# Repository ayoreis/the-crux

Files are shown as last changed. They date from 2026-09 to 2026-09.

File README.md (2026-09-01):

# The Crux

A minimal 3x10 ortholinear keyboard. Driven by a RP2040 with [RMK](https://rmk.rs) + [Vial](https://get.vial.today).

I've always wanted to make a keyboard, I actually started this one with much more ambitious ideas (you can find them in my earlier journals, or by going back the commit history) but realized I should start out with something simpler. So I made this! It was quite nice, and maybe I'll improve it with my previous ideas one-by-one :)

Schematic
PCB
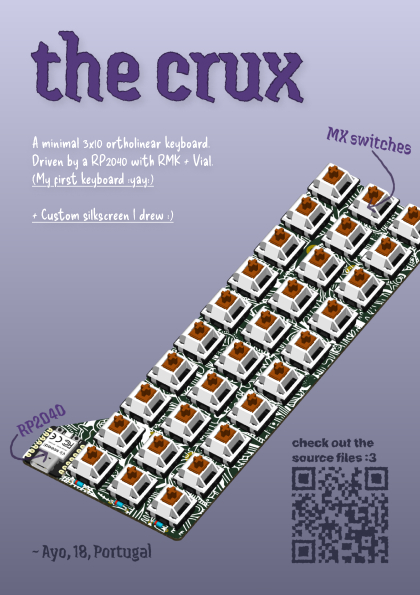
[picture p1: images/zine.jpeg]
Zine


# File structure and assembly

At the top-level there's a general "bom.csv". Then the directories:

- "pcb/" contains a KiCad project and generated production files with KiCAD JLCPCB tools under "pcb/jlcpcb/".
- "standoffs/" contains a FreeCAD file and an exported "standoff.step".
- "images/" contains the images above and the zine in PDF format.
- "firmware/" contains the RMK and Vial firmware. With the compiled UF2 file at "firmware/The_Crux.uf2".

The standoffs are press-fit into the PCB, it's parametric so it can be tuned for different 3D printers.

---

_[Also see this project on Fallout.](https://fallout.hackclub.com/projects/4383)_

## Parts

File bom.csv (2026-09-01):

Description | Cost | Count | Link | Notes
PCB | €24.95 | 1 | https://jlcpcb.com/ | Including shipping
Seeed Studio XIAO RP2040 | €16.27 | 1 | https://pt.farnell.com/seeed-studio/102010428/xiao-board-arm-arduino-board/dp/4060348 | Including shipping
Switches | €17.27 | 3 | https://deltakeyco.com/products/cherry-mx2a-black?variant=49356598411605 | Including shipping
Keycaps | €14.38 | 1 | https://pt.aliexpress.com/item/4000354001038.html | Including shipping
Standoffs | €0.00 | 1 | N/A | 3D printed at home
Total | €72.87

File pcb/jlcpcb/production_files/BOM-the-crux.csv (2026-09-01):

Comment | Designator | Footprint | LCSC | Quantity
XIAO-RP2040-SMD | U1 | XIAO-RP2040-SMD |  | 1
SW_Push | SW30 | SW_Cherry_MX_1.00u_PCB |  | 1
SW_Push | SW29 | SW_Cherry_MX_1.00u_PCB |  | 1
SW_Push | SW28 | SW_Cherry_MX_1.00u_PCB |  | 1
SW_Push | SW27 | SW_Cherry_MX_1.00u_PCB |  | 1
SW_Push | SW26 | SW_Cherry_MX_1.00u_PCB |  | 1
SW_Push | SW25 | SW_Cherry_MX_1.00u_PCB |  | 1
SW_Push | SW24 | SW_Cherry_MX_1.00u_PCB |  | 1
SW_Push | SW23 | SW_Cherry_MX_1.00u_PCB |  | 1
SW_Push | SW22 | SW_Cherry_MX_1.00u_PCB |  | 1
SW_Push | SW21 | SW_Cherry_MX_1.00u_PCB |  | 1
SW_Push | SW20 | SW_Cherry_MX_1.00u_PCB |  | 1
SW_Push | SW19 | SW_Cherry_MX_1.00u_PCB |  | 1
SW_Push | SW18 | SW_Cherry_MX_1.00u_PCB |  | 1
SW_Push | SW17 | SW_Cherry_MX_1.00u_PCB |  | 1
SW_Push | SW16 | SW_Cherry_MX_1.00u_PCB |  | 1
SW_Push | SW15 | SW_Cherry_MX_1.00u_PCB |  | 1
SW_Push | SW14 | SW_Cherry_MX_1.00u_PCB |  | 1
SW_Push | SW13 | SW_Cherry_MX_1.00u_PCB |  | 1
SW_Push | SW12 | SW_Cherry_MX_1.00u_PCB |  | 1
SW_Push | SW11 | SW_Cherry_MX_1.00u_PCB |  | 1
SW_Push | SW10 | SW_Cherry_MX_1.00u_PCB |  | 1
SW_Push | SW9 | SW_Cherry_MX_1.00u_PCB |  | 1
SW_Push | SW8 | SW_Cherry_MX_1.00u_PCB |  | 1
SW_Push | SW7 | SW_Cherry_MX_1.00u_PCB |  | 1
SW_Push | SW6 | SW_Cherry_MX_1.00u_PCB |  | 1
SW_Push | SW5 | SW_Cherry_MX_1.00u_PCB |  | 1
SW_Push | SW4 | SW_Cherry_MX_1.00u_PCB |  | 1
SW_Push | SW3 | SW_Cherry_MX_1.00u_PCB |  | 1
SW_Push | SW2 | SW_Cherry_MX_1.00u_PCB |  | 1
SW_Push | SW1 | SW_Cherry_MX_1.00u_PCB |  | 1
D | D4 | D_DO-35_SOD27_P7.62mm_Horizontal |  | 1
D | D11 | D_DO-35_SOD27_P7.62mm_Horizontal |  | 1
D | D3 | D_DO-35_SOD27_P7.62mm_Horizontal |  | 1
D | D27 | D_DO-35_SOD27_P7.62mm_Horizontal |  | 1
D | D23 | D_DO-35_SOD27_P7.62mm_Horizontal |  | 1
D | D30 | D_DO-35_SOD27_P7.62mm_Horizontal |  | 1
D | D25 | D_DO-35_SOD27_P7.62mm_Horizontal |  | 1
D | D7 | D_DO-35_SOD27_P7.62mm_Horizontal |  | 1
D | D14 | D_DO-35_SOD27_P7.62mm_Horizontal |  | 1
D | D2 | D_DO-35_SOD27_P7.62mm_Horizontal |  | 1
D | D26 | D_DO-35_SOD27_P7.62mm_Horizontal |  | 1
D | D5 | D_DO-35_SOD27_P7.62mm_Horizontal |  | 1
D | D19 | D_DO-35_SOD27_P7.62mm_Horizontal |  | 1
D | D8 | D_DO-35_SOD27_P7.62mm_Horizontal |  | 1
D | D15 | D_DO-35_SOD27_P7.62mm_Horizontal |  | 1
D | D12 | D_DO-35_SOD27_P7.62mm_Horizontal |  | 1
D | D18 | D_DO-35_SOD27_P7.62mm_Horizontal |  | 1
D | D10 | D_DO-35_SOD27_P7.62mm_Horizontal |  | 1
D | D22 | D_DO-35_SOD27_P7.62mm_Horizontal |  | 1
D | D29 | D_DO-35_SOD27_P7.62mm_Horizontal |  | 1
D | D6 | D_DO-35_SOD27_P7.62mm_Horizontal |  | 1
D | D24 | D_DO-35_SOD27_P7.62mm_Horizontal |  | 1
D | D13 | D_DO-35_SOD27_P7.62mm_Horizontal |  | 1
D | D17 | D_DO-35_SOD27_P7.62mm_Horizontal |  | 1
D | D28 | D_DO-35_SOD27_P7.62mm_Horizontal |  | 1
D | D1 | D_DO-35_SOD27_P7.62mm_Horizontal |  | 1
D | D20 | D_DO-35_SOD27_P7.62mm_Horizontal |  | 1
D | D21 | D_DO-35_SOD27_P7.62mm_Horizontal |  | 1
D | D16 | D_DO-35_SOD27_P7.62mm_Horizontal |  | 1
D | D9 | D_DO-35_SOD27_P7.62mm_Horizontal |  | 1

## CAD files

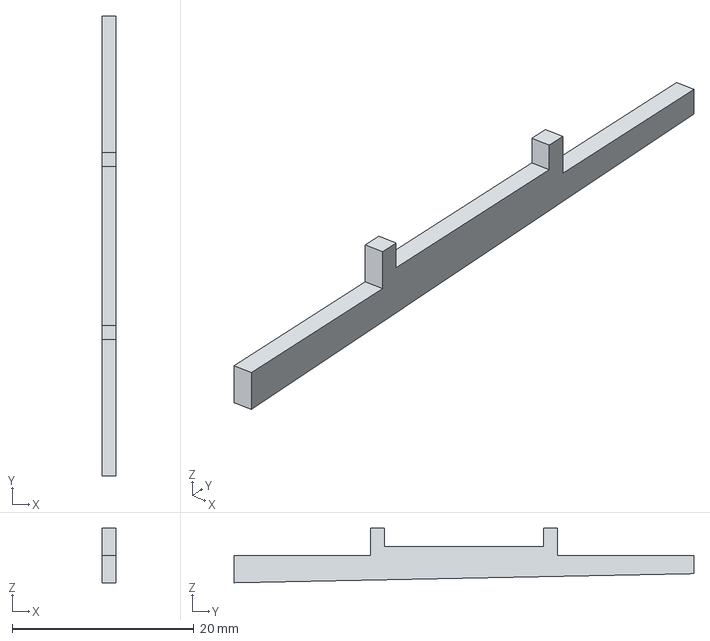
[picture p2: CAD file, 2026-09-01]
standoffs/standoffs.step
1.56 x 50.6 x 6.00 mm

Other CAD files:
standoffs/standoffs.FCStd

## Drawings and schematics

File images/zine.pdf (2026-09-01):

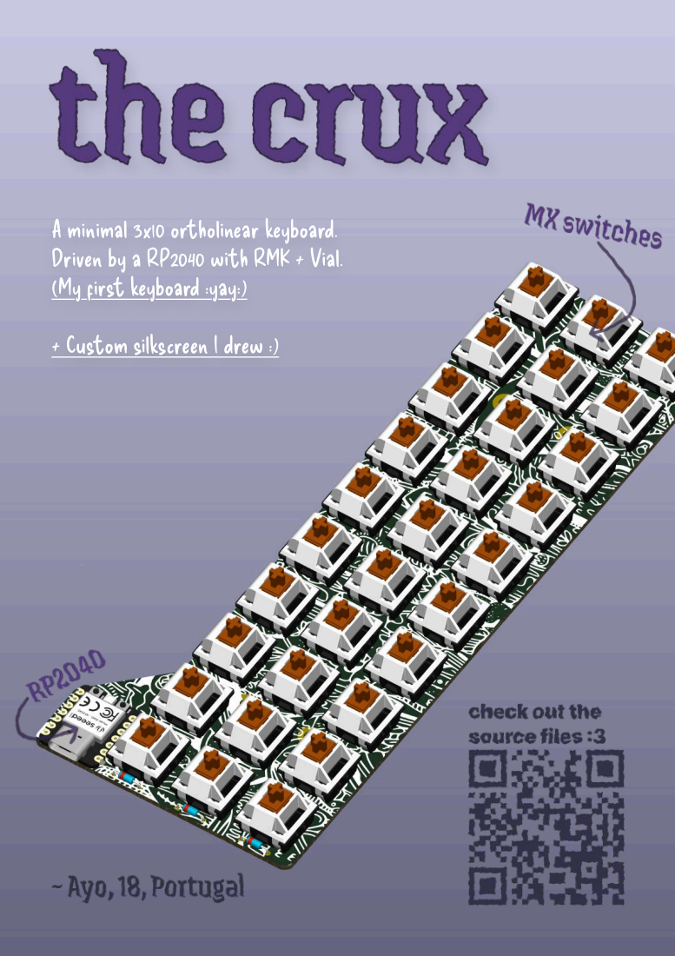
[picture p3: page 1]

A minimal 3x10 ortholinear keyboard.
Driven by a RP2040 wi th RMK + Vial.
(My first keyboard :yay:)

+ Custom silkscreen I drew :)

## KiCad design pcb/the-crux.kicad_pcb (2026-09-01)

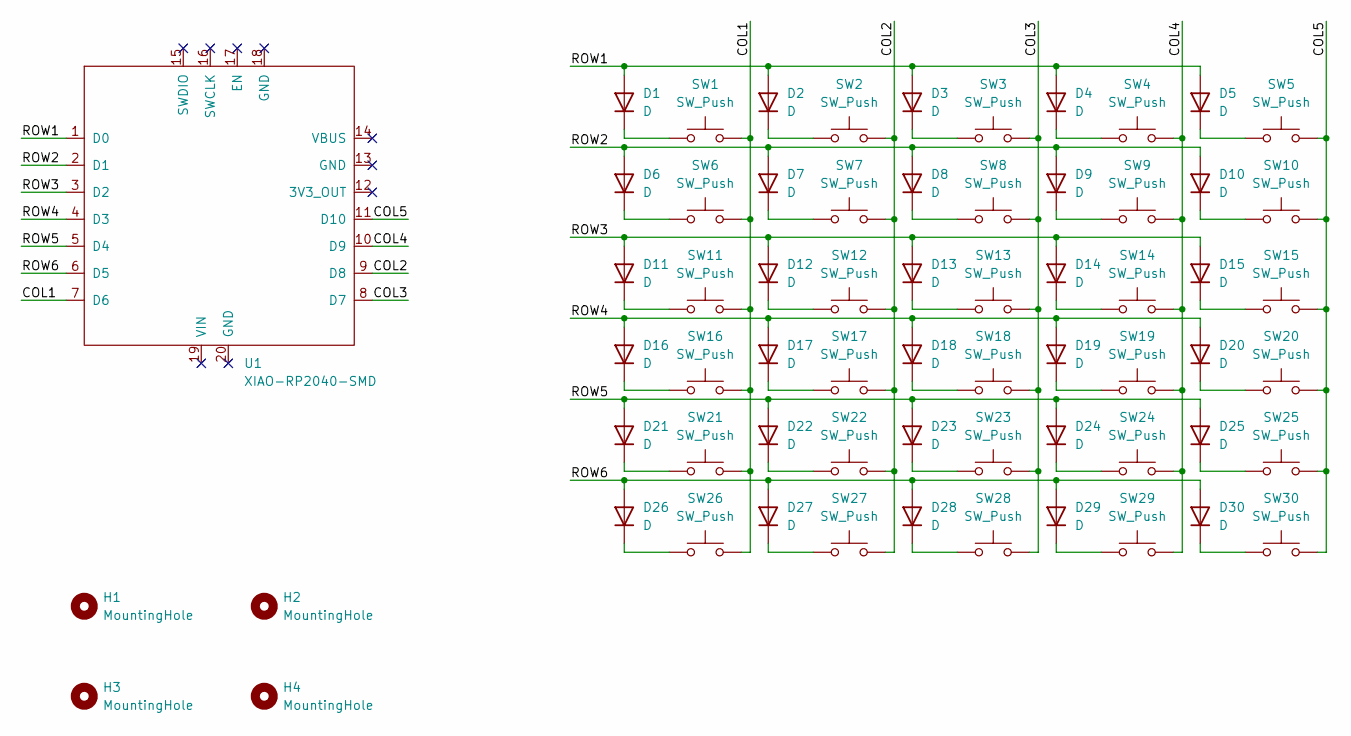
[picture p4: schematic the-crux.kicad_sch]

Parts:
D1, D2, D3, D4, D5, D6, D7, D8, D9, D10, D11, D12, D13, D14, D15, D16, D17, D18, D19, D20, D21, D22, D23, D24, D25, D26, D27, D28, D29, D30: D; D_DO-35_SOD27_P7.62mm_Horizontal
H1, H2, H3, H4: MountingHole; MountingHole_2.2mm_M2_Pad
SW1, SW2, SW3, SW4, SW5, SW6, SW7, SW8, SW9, SW10, SW11, SW12, SW13, SW14, SW15, SW16, SW17, SW18, SW19, SW20, SW21, SW22, SW23, SW24, SW25, SW26, SW27, SW28, SW29, SW30: SW_Push; SW_Cherry_MX_1.00u_PCB
U1: XIAO-RP2040-SMD

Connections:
/COL1: SW1.2, SW6.2, SW11.2, SW16.2, SW21.2, SW26.2, U1.7 (D6)
/COL2: SW2.2, SW7.2, SW12.2, SW17.2, SW22.2, SW27.2, U1.9 (D8)
/COL3: SW3.2, SW8.2, SW13.2, SW18.2, SW23.2, SW28.2, U1.8 (D7)
/COL4: SW4.2, SW9.2, SW14.2, SW19.2, SW24.2, SW29.2, U1.10 (D9)
/COL5: SW5.2, SW10.2, SW15.2, SW20.2, SW25.2, SW30.2, U1.11 (D10)
/ROW1: D1.2 (A), D2.2 (A), D3.2 (A), D4.2 (A), D5.2 (A), U1.1 (D0)
/ROW2: D6.2 (A), D7.2 (A), D8.2 (A), D9.2 (A), D10.2 (A), U1.2 (D1)
/ROW3: D11.2 (A), D12.2 (A), D13.2 (A), D14.2 (A), D15.2 (A), U1.3 (D2)
/ROW4: D16.2 (A), D17.2 (A), D18.2 (A), D19.2 (A), D20.2 (A), U1.4 (D3)
/ROW5: D21.2 (A), D22.2 (A), D23.2 (A), D24.2 (A), D25.2 (A), U1.5 (D4)
/ROW6: D26.2 (A), D27.2 (A), D28.2 (A), D29.2 (A), D30.2 (A), U1.6 (D5)
unnamed: D1.1 (K), SW1.1
unnamed: D2.1 (K), SW2.1
unnamed: D3.1 (K), SW3.1
unnamed: D4.1 (K), SW4.1
unnamed: D5.1 (K), SW5.1
unnamed: D6.1 (K), SW6.1
unnamed: D7.1 (K), SW7.1
unnamed: D8.1 (K), SW8.1
unnamed: D9.1 (K), SW9.1
unnamed: D10.1 (K), SW10.1
unnamed: D11.1 (K), SW11.1
unnamed: D12.1 (K), SW12.1
unnamed: D13.1 (K), SW13.1
unnamed: D14.1 (K), SW14.1
unnamed: D15.1 (K), SW15.1
unnamed: D16.1 (K), SW16.1
unnamed: D17.1 (K), SW17.1
unnamed: D18.1 (K), SW18.1
unnamed: D19.1 (K), SW19.1
unnamed: D20.1 (K), SW20.1
unnamed: D21.1 (K), SW21.1
unnamed: D22.1 (K), SW22.1
unnamed: D23.1 (K), SW23.1
unnamed: D24.1 (K), SW24.1
unnamed: D25.1 (K), SW25.1
unnamed: D26.1 (K), SW26.1
unnamed: D27.1 (K), SW27.1
unnamed: D28.1 (K), SW28.1
unnamed: D29.1 (K), SW29.1
unnamed: D30.1 (K), SW30.1

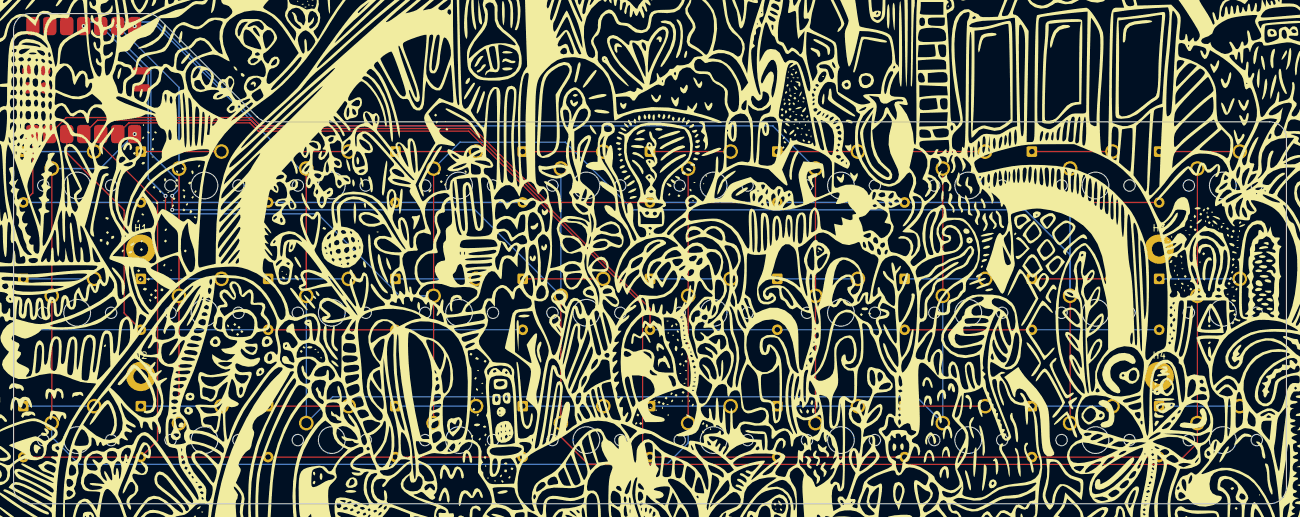
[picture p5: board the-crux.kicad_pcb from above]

Board: 2 copper layers, 190.5 x 73.4 mm, 65 parts (0 on the bottom side), 41 nets.

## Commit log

2025-12-31 Initialise project
    [keyboard.kicad_pcb, keyboard.kicad_sch]
2026-01-06 Name project and add README
    [the-crux.kicad_pcb, the-crux.kicad_sch]
2026-01-07 Design symbols for DRV5056 and SK6812MINI-E
    [the-crux.kicad_sch]
2026-01-09 Wire LEDs
    [leds.kicad_sch, the-crux.kicad_sch]
2026-01-11 Wire linear hall-effect sensors and analog multiplexers
    [linear-hall-effect-sensors.kicad_sch, the-crux.kicad_sch]
2026-01-19 Design footprint for GATERON Low Profile Magnetic switch
2026-01-19 Wire switches
    [switches.kicad_sch, the-crux.kicad_sch]
2026-01-19 Design footprint for SK6812MINI-E
2026-01-20 Fix symbols and footprints
    [leds.kicad_sch, linear-hall-effect-sensors.kicad_sch]
2026-08-11 Snapshot previous progress
    [leds.kicad_sch, linear-hall-effect-sensors.kicad_sch, the-crux.kicad_pcb]
2026-09-01 Do all the stuff
    [BOM-the-crux.csv, bom.csv, leds.kicad_sch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]
2026-09-01 Remove KiCad history directory
2026-10-16 Make case
